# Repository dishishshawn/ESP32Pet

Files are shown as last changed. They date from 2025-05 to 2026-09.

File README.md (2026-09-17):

# ESP32PET

An open-source Tamagotchi, built on an ESP32 with an ST7735 LCD and physical buttons. 
A digital pet resembling me responds to feeding, playing, and dressing up. 
Stats are persistent (saved to EEPROM)

## Features
- Deep sleep (Battery powered use)
- Three-button UI (+ 1 for on and off)
- Designed for portable use

## Hardware Requirements
- ESP32 w/ EEPROM storage (ESP32 DevKit V1)
- Arduino framework (Platform IO)
- TFT LCD (ST7735)
- 3.7V LiPo battery + MCP1700 (3.3V LDO)
- 4x momentary push buttons

## Applications
- KiCAD
- Arduino IDE or PlatformIO

## Additional Notes
Decided to use the full esp32 dev kit for easy testing of new firmware/features.

## Images



## Schematic

**Top level**

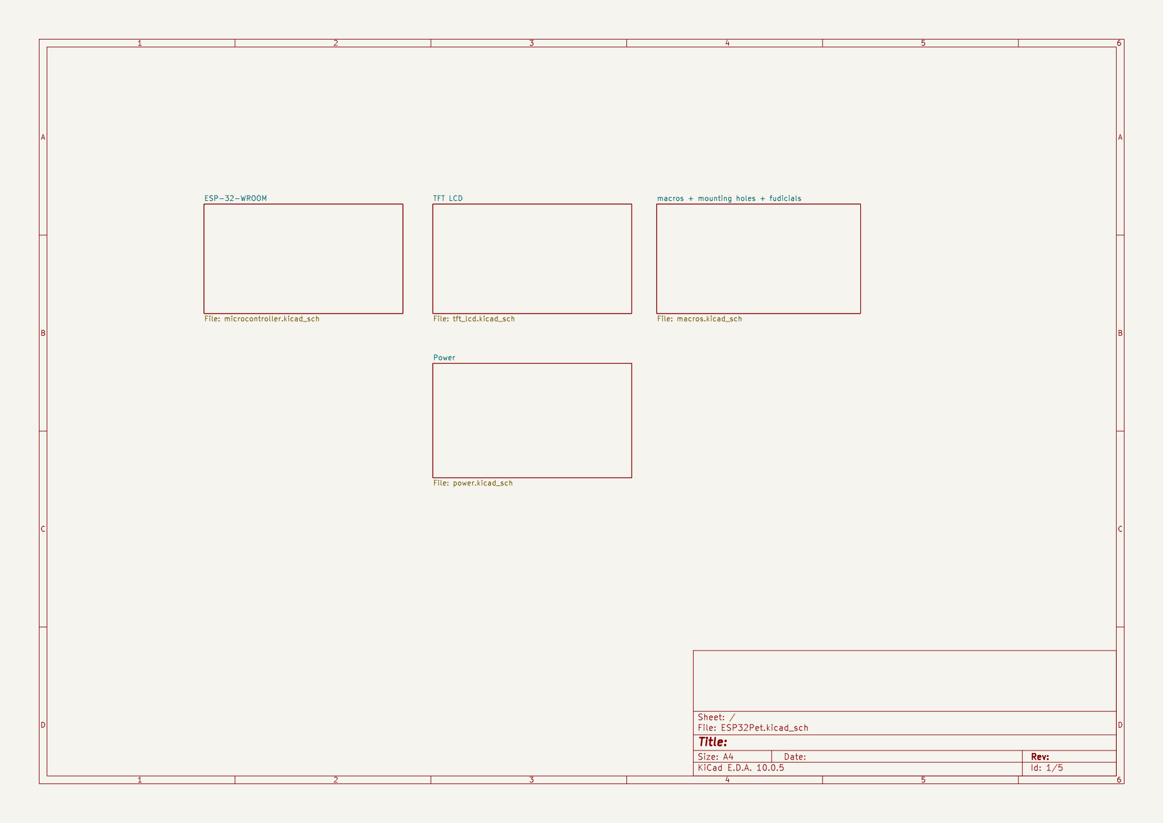
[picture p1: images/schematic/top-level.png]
Top-level schematic


**ESP32**

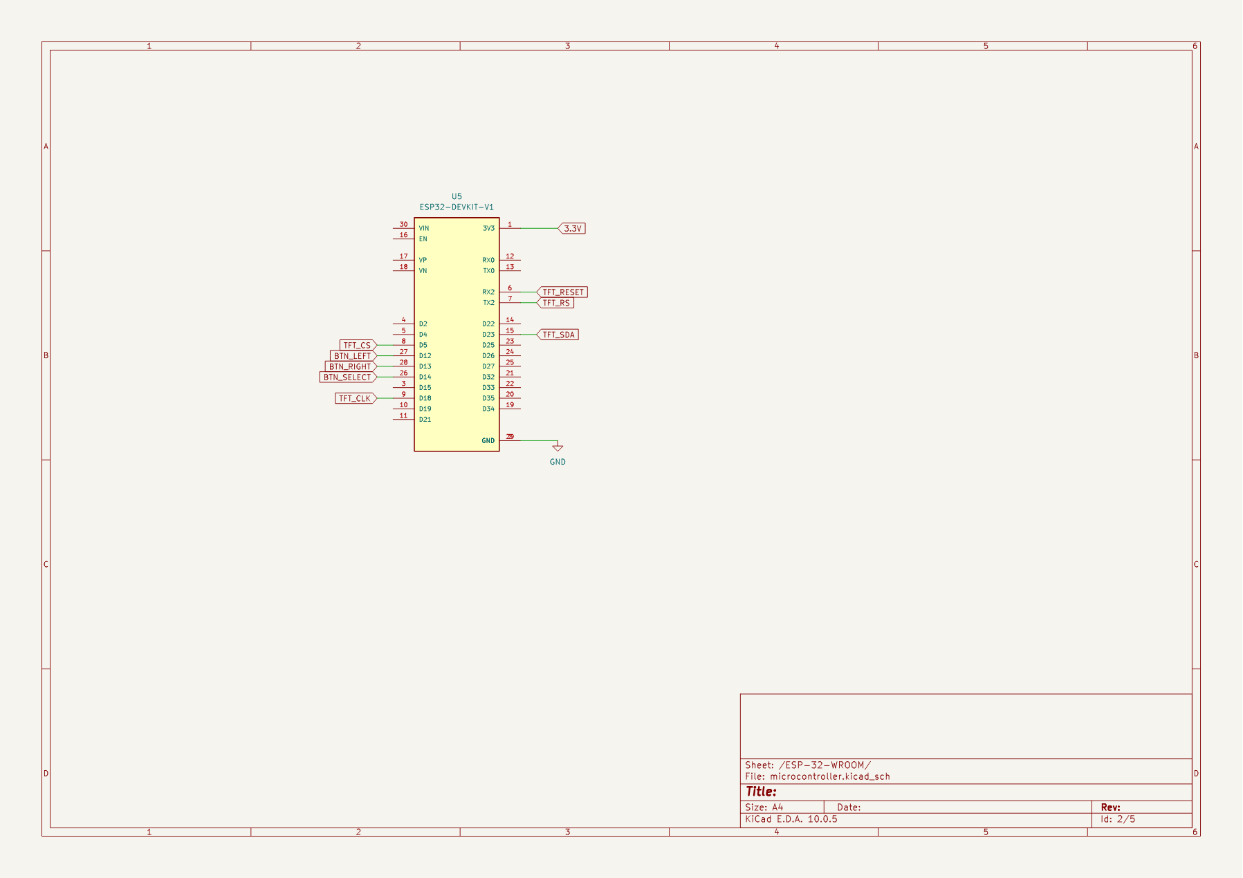
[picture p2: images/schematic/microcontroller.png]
ESP32 schematic


**Power**

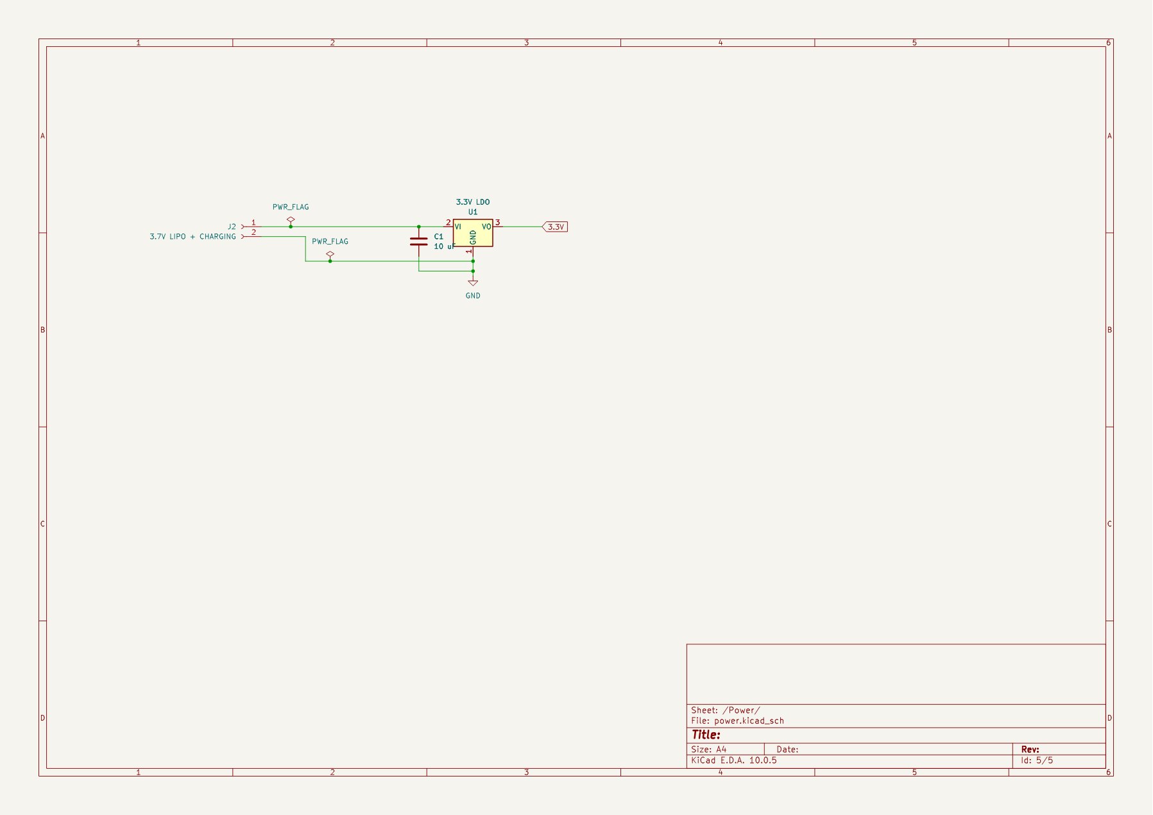
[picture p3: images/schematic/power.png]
Power schematic


**TFT LCD**

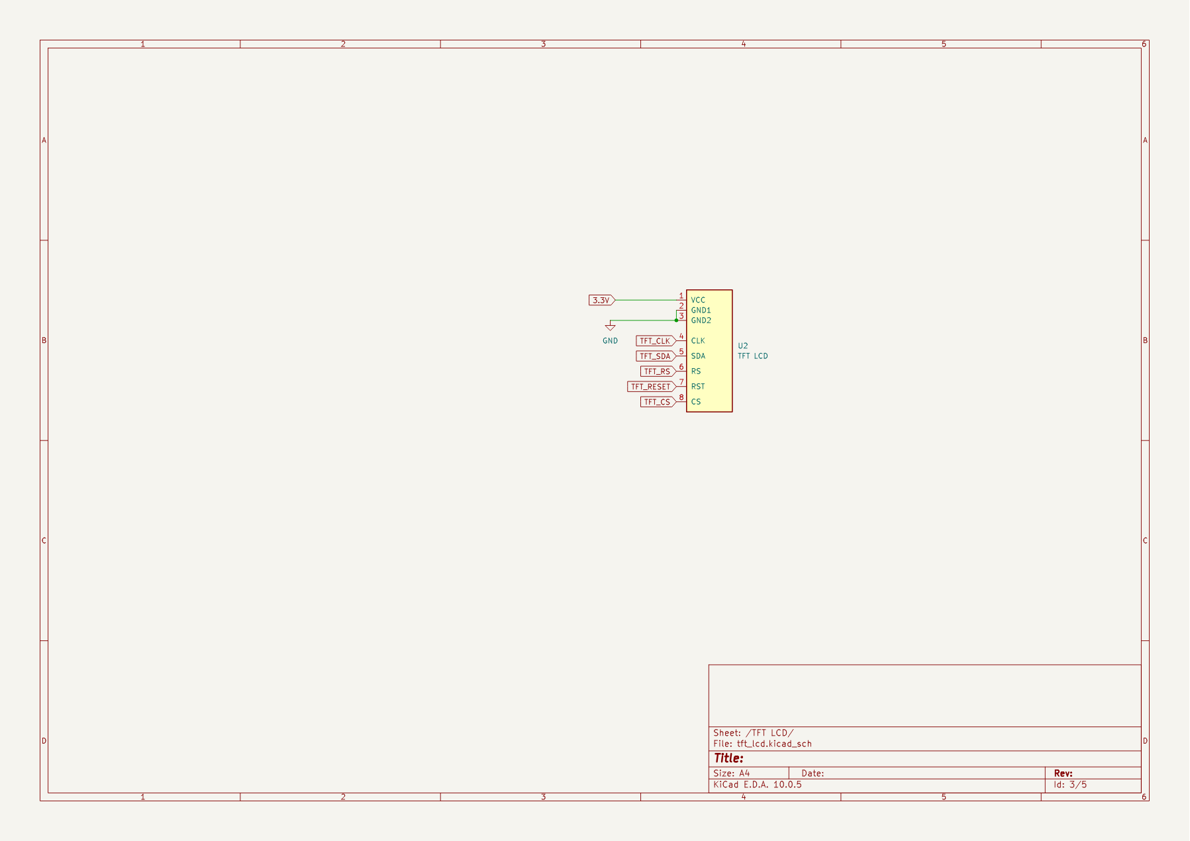
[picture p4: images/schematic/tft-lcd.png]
TFT LCD schematic


## Tamagotchi Case
[OnShape](https://cad.onshape.com/documents/7b0af2517bc8518bf7fb4dfa/w/fc1d8dcb5d67add2eca69795/e/ab74bcbcb7495b5b308ae66d)

## Demo

No demo currently

## Sponsorship


PCBWay sponsors 3D Printing and PCB assembly costs on this project during the prototyping phase!
If you are interested in their awesome fabrication services please check them out.  They offer
3D prototyping, PCB design, and assembly, as well as CNC metal fabrication.  Costs are reasonable and the quality is as good as it gets.  Thank you, PCBWay, for sponsoring me!

## License

MIT

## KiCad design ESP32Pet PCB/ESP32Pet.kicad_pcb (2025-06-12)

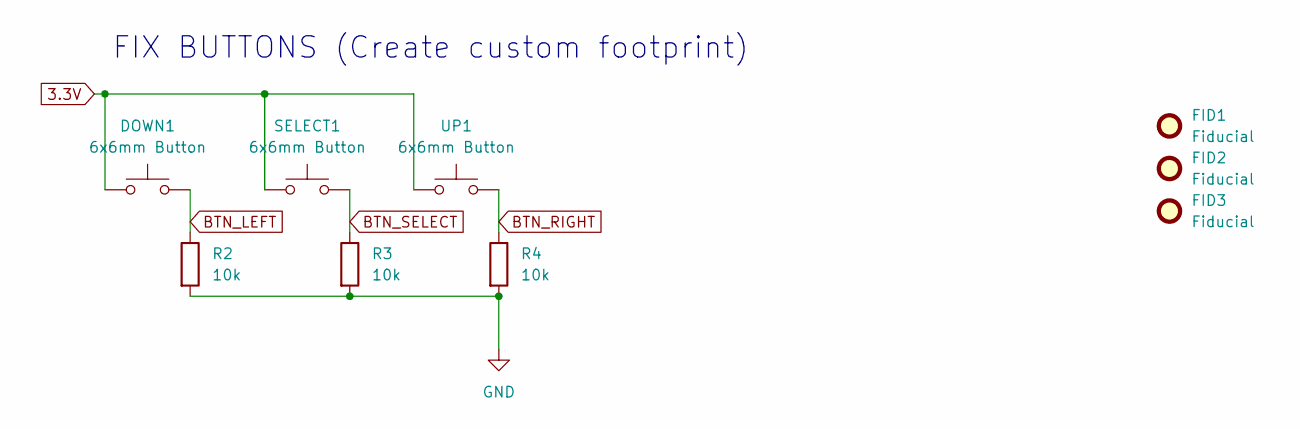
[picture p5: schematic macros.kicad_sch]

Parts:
DOWN1: 6x6mm Button; SW_PUSH_6mm_H5mm
FID1, FID2, FID3: Fiducial; Fiducial_0.5mm_Mask1mm
R2, R3, R4: 10k; R_Axial_DIN0204_L3.6mm_D1.6mm_P7.62mm_Horizontal
SELECT1: 6x6mm Button; SW_PUSH_6mm_H5mm
UP1: 6x6mm Button; SW_PUSH_6mm_H5mm

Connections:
3.3V: DOWN1.1, SELECT1.1, UP1.1; also elsewhere on the board
BTN_LEFT: DOWN1.2, R2.1; also elsewhere on the board
BTN_RIGHT: R4.1, UP1.2; also elsewhere on the board
BTN_SELECT: R3.1, SELECT1.2; also elsewhere on the board
GND: R2.2, R3.2, R4.2; also elsewhere on the board

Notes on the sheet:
FIX BUTTONS (Create custom footprint)

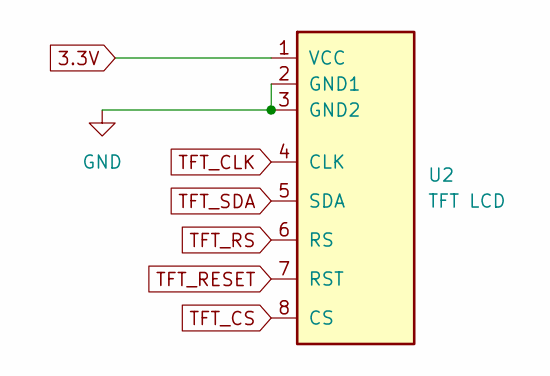
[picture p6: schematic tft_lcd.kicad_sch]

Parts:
U2: TFT LCD; TFT LCD 1.8inch 128x160 w_ SD Card Slot

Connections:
3.3V: U2.1 (VCC); also elsewhere on the board
GND: U2.2 (GND1), U2.3 (GND2); also elsewhere on the board
TFT_CLK: U2.4 (CLK); also elsewhere on the board
TFT_CS: U2.8 (CS); also elsewhere on the board
TFT_RESET: U2.7 (RST); also elsewhere on the board
TFT_RS: U2.6 (RS); also elsewhere on the board
TFT_SDA: U2.5 (SDA); also elsewhere on the board

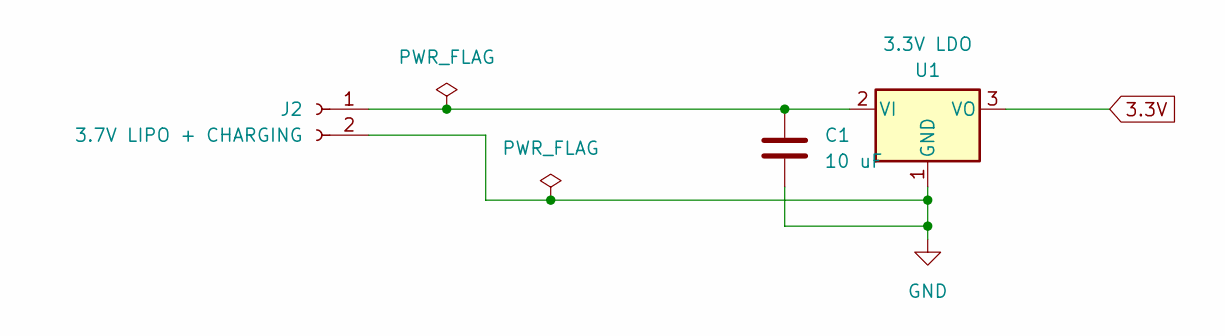
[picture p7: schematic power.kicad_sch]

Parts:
C1: 10 uF; CP_Radial_D4.0mm_P1.50mm
J2: 3.7V LIPO + CHARGING; PinHeader_1x02_P2.54mm_Vertical
U1: 3.3V LDO; TO-92_Inline

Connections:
3.3V: U1.3 (VO); also elsewhere on the board
GND: C1.1, J2.2, U1.1 (GND); also elsewhere on the board
unnamed: C1.2, J2.1, U1.2 (VI)

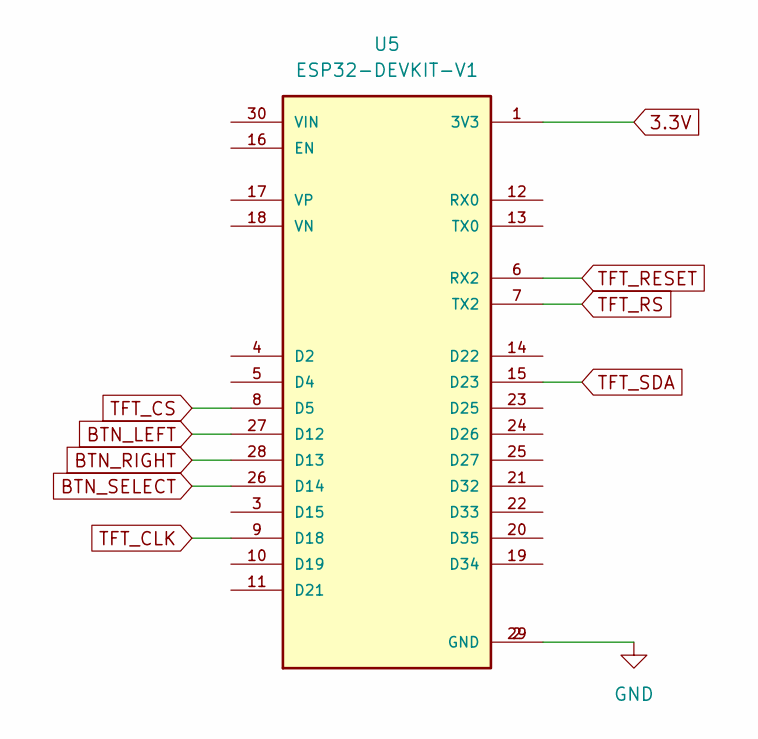
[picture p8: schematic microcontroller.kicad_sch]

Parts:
U5: ESP32-DEVKIT-V1; MODULE_ESP32_DEVKIT_V1; PARTREV N/A

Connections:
3.3V: U5.1 (3V3); also elsewhere on the board
BTN_LEFT: U5.27 (D12); also elsewhere on the board
BTN_RIGHT: U5.28 (D13); also elsewhere on the board
BTN_SELECT: U5.26 (D14); also elsewhere on the board
GND: U5.2 (GND), U5.29 (GND); also elsewhere on the board
TFT_CLK: U5.9 (D18); also elsewhere on the board
TFT_CS: U5.8 (D5); also elsewhere on the board
TFT_RESET: U5.6 (RX2); also elsewhere on the board
TFT_RS: U5.7 (TX2); also elsewhere on the board
TFT_SDA: U5.15 (D23); also elsewhere on the board

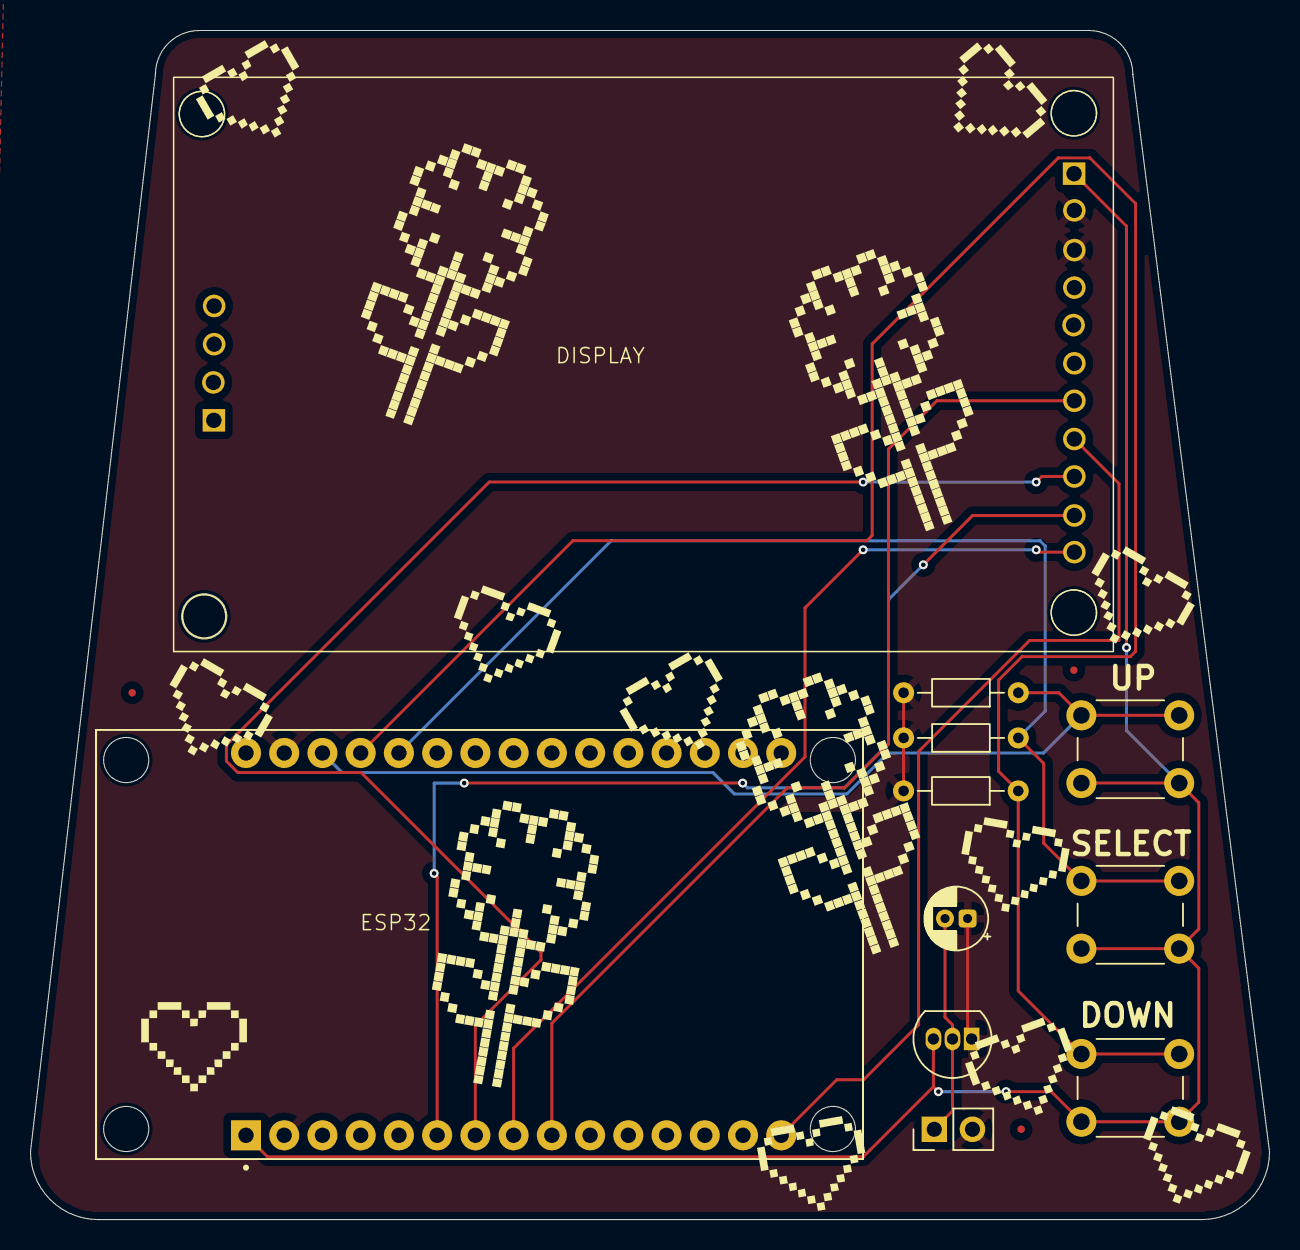
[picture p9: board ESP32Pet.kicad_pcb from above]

Board: 2 copper layers, 82.3 x 79.0 mm, 14 parts (0 on the bottom side), 11 nets.

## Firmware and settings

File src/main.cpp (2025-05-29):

#include <Arduino.h>
#include <TFT_eSPI.h>
#include "esp_task_wdt.h"
#include <EEPROM.h>

#include "gotchi.h"
#include "scroll_menu.h"
#include "sprites.h"

TFT_eSPI tft = TFT_eSPI();
hw_timer_t * timer = NULL;

#define LEFT 14
#define RIGHT 13
#define SELECT 12
#define WAKE_UP_PIN 34

void stateSelection();
void homeFunc();
void sleepFunc();
void dressFunc();
void statsFunc();
void changeState(const char* section);
void displayMenuFunc();
void displayGotchi();
void displaySleep();
void displayEat();
void displayPlay();
void displayCut();
void displayAge();
void displayMenuDress();
void displayStats();
// void IRAM_ATTR watchdogCallback();

ScrollMenu menu(58, 32, 6);
ScrollMenu menuDress(58, 32, 5);
char activeState[20] = "Home";

bool sleeping;
int sleepLevel;
int happiness;
int hunger;
int age;
int beardLength;
int expression;
int clothing;

Gotchi gotchi(false, 0, 0, 0, 0, 0, 0, 0);

unsigned long lastInteraction = 0;
const unsigned long timeoutDuration = 10000;
bool pressed = false;
int frameCount = 0;
int spriteOffset = -1;

#define BAR_W 16
inline void clearOutside() {
    tft.resetViewport();                       // turn clipping OFF
    tft.fillRect(0, 0, BAR_W, 128, TFT_BLACK);           // left bar
    tft.fillRect(160-BAR_W, 0, BAR_W, 128, TFT_BLACK);   // right bar
    tft.setViewport(16, 0, 143, 127, true);    // clipping ON again
}

void setup() {
    Serial.begin(115200);
    EEPROM.begin(32);
    Serial.println("Boot");

    esp_sleep_wakeup_cause_t wakeup_reason = esp_sleep_get_wakeup_cause();
    Serial.print("Wake reason: ");
    Serial.println(wakeup_reason);

    sleeping     = EEPROM.read(0);
    sleepLevel   = EEPROM.read(1);
    happiness    = EEPROM.read(2);
    hunger       = EEPROM.read(3);
    EEPROM.get(10, age);
    beardLength  = EEPROM.read(5);
    expression   = EEPROM.read(6);
    clothing     = EEPROM.read(7);

    gotchi = Gotchi(sleeping, sleepLevel, hunger, happiness, age, beardLength, expression, clothing);

    tft.init(INITR_GREENTAB);
    tft.fillScreen(TFT_BLACK);
    tft.setRotation(1);

    bool flip = true;
    int x0 = 16;
    int y0 = 0;
    int x1 = x0 + 128 - 1;
    int y1 = y0 + 128 - 1;
    tft.setViewport(x0, y0, x1, y1, flip); // Set the viewport to the full screen

    tft.fillScreen(TFT_BLACK);

    pinMode(LEFT, INPUT_PULLDOWN);
    pinMode(RIGHT, INPUT_PULLDOWN);
    pinMode(SELECT, INPUT_PULLDOWN);
    pinMode(WAKE_UP_PIN, INPUT_PULLDOWN);

    frameCount = 50;
    displayGotchi();
    displayMenuFunc();
    displayStats();

    // timer = timerBegin(0, 80, true); 
    // timerAttachInterrupt(timer, &watchdogCallback, true);
    // timerAlarmWrite(timer, 1000000, true); // 1 second
    // timerAlarmEnable(timer);


    // esp_task_wdt_init(40, true); 
    // esp_task_wdt_add(NULL); 

    int debugAge = 0;
    EEPROM.get(10, debugAge);

    Serial.println("Ready to start");
    Serial.printf("EEPROM Read:\n Sleep: %d\n Hunger: %d\n Happiness: %d\n Age: %d\n Beard: %d\n Clothing: %d\n",
        sleepLevel, hunger, happiness, age, beardLength, clothing);
}

// States
int state = 0;
/*
    0 - home
    1 - sleep
    2 - dress
    3 - stats
*/

char menuSections[][20] = {
    "Cut",
    "Dress",
    "Eat",
    "Stats",
    "Play",
    "Sleep",
};

const unsigned char* menuIcons[] = {
    beard_icon,
    dress_icon,
    eat_icon,
    stats_icon,
    play_icon,
    sleep_icon,
};

const unsigned char* bodyArray[] = {
    myBitmapbody_01,
    myBitmapbody_02,
    myBitmapbody_03,
    myBitmapbody_04
};

const unsigned char* menuDressIcons[] = {
    backHome,
    myBitmapbody_01,
    myBitmapbody_02,
    myBitmapbody_03,
    myBitmapbody_04
};

void loop() {
    if (digitalRead(WAKE_UP_PIN) == HIGH) {
        Serial.println("Power button pressed. Going to sleep...");
        
        // Save everything
        gotchi.updateSleeping();  // optional, to show it's sleeping
        EEPROM.write(0, gotchi.sleeping);
        EEPROM.write(1, gotchi.sleep);
        EEPROM.write(2, gotchi.happiness);
        EEPROM.write(3, gotchi.hunger);
        EEPROM.put(10, gotchi.age);
        EEPROM.write(5, gotchi.beardLength);
        EEPROM.write(6, gotchi.expression);
        EEPROM.write(7, gotchi.clothing);
        EEPROM.commit();

        delay(500); // debounce
        tft.fillScreen(TFT_BLACK);
        tft.setCursor(20, 20);
        tft.setTextSize(2);
        tft.setTextColor(TFT_WHITE);
        tft.println("Goodnight...");

        delay(2000);
        esp_sleep_enable_ext0_wakeup(static_cast<gpio_num_t>(WAKE_UP_PIN), LOW);
        esp_deep_sleep_start();
    }

    stateSelection(); 
    delay(10);
}

void stateSelection() {
    if(state == 0){
        homeFunc();
    } else if (state == 1) {
        sleepFunc();
    } else if (state == 2) {
        dressFunc();
    } else if (state == 3) {
        statsFunc();
    }
}

// State functions

void changeState(const char* section){
    tft.drawRoundRect(0, 0, 128, 160, 3, TFT_WHITE); // quick outline
    EEPROM.commit();
    lastInteraction = millis();
    delay(200);
    tft.drawRoundRect(0, 0, 128, 160, 3, TFT_BLACK); // erase it  

    Serial.println(section);
    if(strcmp(section, "Sleep") == 0){
        gotchi.updateSleeping();
        gotchi.updateHappiness(0);
        gotchi.updateSleep(0);
        tft.fillRect(0, 16, 128, 160, TFT_BLACK);
        state = 1;
    } else if(strcmp(section, "Play") == 0){
        gotchi.updateHappiness(4);
        gotchi.updateSleep(-2);
        gotchi.updateHunger(-2);
        displayPlay();
    } else if(strcmp(section, "Stats") == 0){
        displayAge();
        state = 3;
    } else if(strcmp(section, "Eat") == 0){
        gotchi.updateHunger(5);
        gotchi.updateHappiness(1);
        displayEat();
    } else if(strcmp(section, "Cut") == 0){
        gotchi.updateBeardLength(0);
        if(gotchi.beardLength >= 24){
        gotchi.updateHappiness(10);
        }
        displayCut();
    } else if(strcmp(section, "Dress") == 0){
        tft.fillRect(0, 16, 128, 48, TFT_BLACK);
        displayMenuDress();
        state = 2;
    } else if(strcmp(section, "Home") == 0){
        frameCount = 50;
        tft.fillRect(0, 16, 128, 48, TFT_BLACK);
        displayMenuFunc();
        displayGotchi();
        state = 0;
    }
    for (int i = 0; i < 20; i++){
    activeState[i] = section[i]; 
    }
    pressed = false;
    displayStats();
}

void homeFunc() {
    if(pressed == false) {
        if(digitalRead(SELECT) == HIGH) {
            pressed = true;
            changeState(menuSections[menu.activeSection]);
    } else if(digitalRead(LEFT) == HIGH) {
            pressed = true;
            menu.moveLeft();
            displayMenuFunc();
        } else if(digitalRead(RIGHT) == HIGH) {
            pressed = true;
            menu.moveRight();
            displayMenuFunc();
        }
    } else if(digitalRead(SELECT) == LOW && digitalRead(LEFT) == LOW && digitalRead(RIGHT) == LOW) {
            pressed = false;
        }
    displayGotchi();
}

void sleepFunc() {
    if(!gotchi.sleeping) {
        changeState("Home");
    }

    if(!pressed) {
        if(digitalRead(SELECT) == HIGH) {
            pressed = true;
            gotchi.updateSleeping();
            gotchi.updateHappiness(-3);
            changeState("Home");
        } else if(digitalRead(SELECT) == LOW && digitalRead(LEFT) == LOW && digitalRead(RIGHT) == LOW) {
        pressed = false;
    }
    displaySleep();
    }
}

void dressFunc() {

    if (!pressed) {

        if (digitalRead(SELECT) == HIGH) {          // SELECT
            pressed = true;

            if (menuDress.activeSection == 0) {     // “← Home”
                changeState("Home");
            } else {                                // one of the outfits
                gotchi.updateClothing(menuDress.activeSection - 1);
                changeState("Home");
            }

        } else if (digitalRead(LEFT) == HIGH) {     // LEFT
            pressed = true;
            menuDress.moveLeft();
            displayMenuDress();

        } else if (digitalRead(RIGHT) == HIGH) {    // RIGHT
            pressed = true;
            menuDress.moveRight();
            displayMenuDress();
        }
    }

    else if (digitalRead(SELECT) == LOW &&
             digitalRead(LEFT)   == LOW &&
             digitalRead(RIGHT)  == LOW) {
        pressed = false;
    }
}

void statsFunc(){
  if(pressed == false){
    if(digitalRead(SELECT) == HIGH){
      pressed = true;
      changeState("Home");    
    }
  }else if(digitalRead(SELECT) == LOW && digitalRead(LEFT) == LOW && digitalRead(RIGHT) == LOW){
    pressed = false;
  }  
}

void displayMenuFunc()
{
    int y = 17;
    const int rowH = 16;

    tft.fillRect(51, 17, 77, 47, TFT_BLACK);
    tft.setTextColor(TFT_WHITE, TFT_BLACK);
    tft.setTextSize(1);

    /* ── previous ─────────────────────────── */
    tft.setCursor(menu.x + 19, y + 4);
    tft.println(menuSections[ menu.prev() ]);
    tft.drawBitmap(menu.x, y + 3, menuIcons[ menu.prev() ], 10, 10, 1);

    /* ── active ───────────────────────────── */
    y += rowH;
    tft.drawRoundRect(menu.x - 5, y, 73, rowH, 3, TFT_WHITE);
    tft.setCursor(menu.x + 19, y + 4);
    tft.println(menuSections[ menu.activeSection ]);
    tft.drawBitmap(menu.x, y + 3, menuIcons[ menu.activeSection ], 10, 10, 1);

    /* ── next ─────────────────────────────── */
    y += rowH;
    tft.setCursor(menu.x + 19, y + 4);
    tft.println(menuSections[ menu.next() ]);
    tft.drawBitmap(menu.x, y + 3, menuIcons[ menu.next() ], 10, 10, 1);
}

// void displayMenuFunc(){
//   int y = 17;
//   int height = 16;

//   tft.fillRect(51, 17, 77, 47, TFT_BLACK);
//   tft.setTextColor(TFT_WHITE, TFT_BLACK);
  
//   tft.setTextSize(1);

//   //PREV SECTION
//   tft.setCursor(menu.x + 19, y + 4);
//   tft.println(menuSections[menu.prev()]);
//   tft.drawBitmap(menu.x, y + 3, menuIcons[menu.prev()], 10, 10, 1);

//   //ACTIVE SECTION
//   y = y + height;
//   tft.drawRoundRect(menu.x - 5, y, 73, 16, 3, TFT_WHITE);
//   tft.setCursor(menu.x + 19, y + 4);
//   tft.println(menuSections[menu.next()]);
//   tft.drawBitmap(menu.x, y + 3, menuIcons[menu.next()], 10, 10, 1);

//   //NEXT SECTION
//   y = y + height;
//   tft.setCursor(menu.x + 19, y + 4);
//   tft.println(menuSections[menu.nextSection]);
//   tft.drawBitmap(menu.x, y + 3, menuIcons[menu.nextSection], 10, 10, 1);
// }


void displayMenuDress(){
  tft.fillRect(1, 17, 127, 47, TFT_BLACK);

  // PREV CLOTHING
  tft.drawBitmap(3, 17, menuDressIcons[menuDress.prev()], 32, 46, TFT_WHITE);

  // DISPLAY ALE WITH CHANGING CLOTHING
  tft.drawRoundRect(39, 16, 50, 48, 5, TFT_WHITE);
  
  int spriteX = 39 + 10;
  
  if(menuDress.activeSection != 0){
    tft.fillRect(spriteX, 18, 32, 46, TFT_BLACK);
    tft.drawBitmap(spriteX, 18, menuDressIcons[menuDress.activeSection], 32, 46, TFT_WHITE);
  
    tft.drawBitmap(spriteX, 18, feet_bg, 32, 46, TFT_BLACK);
    tft.drawBitmap(spriteX, 18, feet, 32, 46, TFT_WHITE);
    
    tft.drawBitmap(spriteX, 18, head_bg, 32, 46, TFT_BLACK);
    tft.drawBitmap(spriteX, 18, head, 32, 46, TFT_WHITE);
    
    if(gotchi.beardLength >= 24){
      tft.drawBitmap(10, 18 + spriteOffset, beard_bg, 32, 46, TFT_BLACK);
      tft.drawBitmap(10, 18 + spriteOffset, beard, 32, 46, TFT_WHITE);
    }
    
    tft.drawBitmap(spriteX, 18, eyes, 32, 46, TFT_BLACK);
  }else{
    tft.fillRect(spriteX, 18, 32, 46, TFT_BLACK);
    tft.drawBitmap(spriteX, 18, menuDressIcons[menuDress.activeSection], 32, 46, TFT_WHITE);
  }
  
  
  // NEXT CLOTHING
  tft.drawBitmap(93, 17, menuDressIcons[menuDress.next()], 32, 46, TFT_WHITE);
}

void displayGotchi(){

  if(frameCount >= 50){
    tft.drawRoundRect(0, 16, 50, 48, 5, TFT_WHITE);
    
    tft.fillRect(10, 18, 32, 46, TFT_BLACK);
    
    tft.drawBitmap(10, 18 + spriteOffset, bodyArray[gotchi.clothing], 32, 46, TFT_WHITE);
  
    tft.drawBitmap(10, 18, feet_bg, 32, 46, TFT_BLACK);
    tft.drawBitmap(10, 18, feet, 32, 46, TFT_WHITE);

    tft.drawBitmap(10, 18 + spriteOffset, head_bg, 32, 46, TFT_BLACK);
    tft.drawBitmap(10, 18 + spriteOffset, head, 32, 46, TFT_WHITE);
    
    if(gotchi.beardLength >= 24){
      tft.drawBitmap(10, 18 + spriteOffset, beard_bg, 32, 46, TFT_BLACK);
      tft.drawBitmap(10, 18 + spriteOffset, beard, 32, 46, TFT_WHITE);
    }

    tft.drawBitmap(10, 18 + spriteOffset, eyes, 32, 46, TFT_BLACK);
      
    
    if(spriteOffset == -1){
      spriteOffset = -2;
    }else{   
      spriteOffset = -1;
    }
    frameCount = 0;
  }
  frameCount++;
    
}

void displaySleep(){

  if(frameCount >= 50){
    tft.fillRect(0, 16, 128, 48, TFT_BLACK);
    tft.setTextColor(TFT_WHITE, TFT_BLACK);
    tft.setTextSize(1);
    tft.setCursor(64 - spriteOffset, 33 - spriteOffset);
    tft.println("Z");
    tft.setCursor(59 - !spriteOffset, 46 - !spriteOffset);
    tft.println("Z");
    tft.setTextSize(2);
    tft.setCursor(47 - spriteOffset, 26 - !spriteOffset);
    tft.println("Z");
      
    
    spriteOffset = !spriteOffset;
    frameCount = 0;
  }
  frameCount++;    
}

void selectEatFrame(int x, int y, int n){
  if(gotchi.beardLength >= 24){
    if(n == 1){
      tft.drawBitmap(x, y, eat_anim_head_b_1, 45, 40, TFT_WHITE);
    }else{
      tft.drawBitmap(x, y, eat_anim_head_b_2, 45, 40, TFT_WHITE);
    }  
  }else{
    if(n == 1){
      tft.drawBitmap(x, y, eat_anim_head_n_1, 45, 40, TFT_WHITE);
    }else{
      tft.drawBitmap(x, y, eat_anim_head_n_2, 45, 40, TFT_WHITE);
    }    
  }
  
}

void displayEat(){

  int startX = 30;
  int startY = 20;

  tft.fillRect(0, 16, 128, 48, TFT_BLACK); // Clear screen

  // Frame 1
  selectEatFrame(startX,startY,1);
  tft.drawBitmap(startX + 50, startY + 15, eat_anim_food_1, 15, 15, TFT_WHITE);
  

  delay(500);

  // Frame 2
  tft.fillRect(0, 16, 45 + startX, 48, TFT_BLACK);
  selectEatFrame(startX,startY,2); 
  

  delay(500);

  // Frame 3
  tft.fillRect(0, 16, 45 + startX, 48, TFT_BLACK);
  tft.fillRect(45 + startX, 16, 55 + startX, 48, TFT_BLACK);
  selectEatFrame(startX,startY,1);
  tft.drawBitmap(startX + 50, startY + 15, eat_anim_food_2, 15, 15, TFT_WHITE);
  

  delay(500);

  // Frame 4
  tft.fillRect(0, 16, 45 + startX, 48, TFT_BLACK);
  selectEatFrame(startX,startY,2);
  

  delay(500);

  // Frame 5
  tft.fillRect(0, 17, 128, 48, TFT_BLACK);
  tft.fillRect(45 + startX, 16, 55 + startX, 48, TFT_BLACK);
  selectEatFrame(startX,startY,1);
  tft.drawBitmap(startX + 50, startY + 15, eat_anim_food_3, 15, 15, TFT_WHITE);
  

  delay(500);

  // Frame 6
  tft.fillRect(0, 16, 45 + startX, 48, TFT_BLACK);
  selectEatFrame(startX,startY,2);
  

  delay(500);

  // Frame 7
  tft.fillRect(0, 17, 128, 48, TFT_BLACK);
  tft.fillRect(45 + startX, 16, 55 + startX, 48, TFT_BLACK);
  selectEatFrame(startX,startY,1);
  
  esp_task_wdt_reset();

  delay(500);
  delay(500);

  changeState("Home");
  
}

//__________________________________________________ PLAY ANIMATION

void displayPlay(){
  int startX = 50;
  int startY = 17;
  int loop = 2;
  
  for (int i = 0; i <= loop; i++) {
    // Frame 1
    tft.fillRect(0, 16, 128, 48, TFT_BLACK); // Clear Screen
    tft.drawBitmap(startX, startY, play_anim_1, 27, 48, TFT_WHITE);
     
    delay(200);

    // Frame 2
    tft.fillRect(0, 16, 128, 48, TFT_BLACK);
    tft.drawBitmap(startX, startY, play_anim_2, 27, 48, TFT_WHITE);
    
    delay(200);

    // Frame 3
    tft.fillRect(0, 16, 128, 48, TFT_BLACK);
    tft.drawBitmap(startX, startY, play_anim_3, 27, 48, TFT_WHITE);
    
    delay(200);

    // Frame 4
    tft.fillRect(0, 16, 128, 48, TFT_BLACK);
    tft.drawBitmap(startX, startY, play_anim_4, 27, 48, TFT_WHITE);
    
    delay(200);

    // Frame 5
    tft.fillRect(0, 16, 128, 48, TFT_BLACK);
    tft.drawBitmap(startX, startY, play_anim_5, 27, 48, TFT_WHITE);
    
    delay(200);
  }
  
  delay(500);

  changeState("Home");
  
}

//__________________________________________________ CUT ANIMATION

void displayCut(){
  int startX = 45;
  int startY = 24;
  int loop = 2;
  
  for (int i = 0; i <= loop; i++) {
    // Frame 1
    tft.fillRect(0, 16, 128, 48, TFT_BLACK); // Clear Screen 
    tft.drawBitmap(startX, startY, cut_anim_1, 37, 28, TFT_WHITE);
     
    delay(500);

    // Frame 2
    tft.fillRect(0, 16, 128, 48, TFT_BLACK);
    tft.drawBitmap(startX, startY, cut_anim_2, 37, 28, TFT_WHITE);
    
    delay(500);

  }
  
  delay(500);

  changeState("Home");
  
}

//__________________________________________________ DISPLAY AGE

void displayAge(){
  tft.fillRect(0, 16, 128, 48, TFT_BLACK);

  tft.setTextSize(1);
  
  tft.setCursor(10,20);
  tft.setTextColor(TFT_BLACK, TFT_WHITE);
  tft.print("Name");
  tft.setTextColor(TFT_WHITE);
  tft.println(" Shawn");
  
  tft.setCursor(10,32);
  tft.setTextColor(TFT_BLACK, TFT_WHITE);
  tft.print("Age");
  tft.setTextColor(TFT_WHITE);
  tft.print(" ");
  tft.print(gotchi.age/24);
  tft.println(" days");

  tft.setCursor(10,44);
  tft.setTextColor(TFT_BLACK, TFT_WHITE);
  tft.print("Weight");
  tft.setTextColor(TFT_WHITE);
  tft.println(" 88 kg");
}


//__________________________________________________ STATS DISPLAY

void displayStats(){

  tft.fillRect(1, 1, 127, 15, TFT_BLACK);
  tft.setTextSize(1);

  // HAPPINESS STATS
  tft.setCursor(2,5);
  tft.println("H");
  tft.drawRoundRect(9, 6, 27, 6, 1, TFT_WHITE);
  int H = gotchi.mapValue(gotchi.happiness, 27);
  tft.fillRect(10, 7, H, 4, TFT_WHITE);

  // SLEEP STATS
  tft.setCursor(43,5);
  tft.println("S");
  tft.drawRoundRect(50, 6, 27, 6, 1, TFT_WHITE);
  int S = gotchi.mapValue(gotchi.sleep, 27);
  tft.fillRect(51, 7, S, 4, TFT_WHITE);

  // HUNGER/FOOD STATS
  tft.setCursor(85,5);
  tft.println("F");
  tft.drawRoundRect(92, 6, 27, 6, 1, TFT_WHITE);
  int F = gotchi.mapValue(gotchi.hunger, 27);
  tft.fillRect(93, 7, F, 4, TFT_WHITE);
  
  
}

// Timer
// int hour = 40; 
// void IRAM_ATTR watchdogCallback() {
//     sec++;
//     Serial.print("sec: ");
//     Serial.println(sec);

//     if (sec > hour) {
//         sec = 0;

//         gotchi.updateAge();
//         gotchi.updateHappiness(-1);
//         gotchi.updateHunger(-1);
//         gotchi.updateBeardLength(gotchi.beardLength + 1);
//         gotchi.updateSleep(gotchi.sleeping ? 3 : -1);

//         // Save everything and go to sleep
//         EEPROM.commit();

//         Serial.println("Going to deep sleep...");
//         esp_sleep_enable_ext0_wakeup(static_cast<gpio_num_t>(WAKE_UP_PIN), LOW);
//         esp_deep_sleep_start();
//     }
// }


void turnOn() {
  Serial.println("TURN ON");
  delay(2000);
}

void turnOff() {
    tft.fillScreen(TFT_BLACK);
    tft.setTextColor(TFT_WHITE, TFT_BLACK);
    tft.setTextSize(2);
    tft.setCursor(20, 30);
    tft.println("Goodbye!");

    delay(2000);

    // Save data to EEPROM
    EEPROM.write(0, gotchi.sleeping);
    EEPROM.write(1, gotchi.sleep);
    EEPROM.write(2, gotchi.happiness);
    EEPROM.write(3, gotchi.hunger);
    EEPROM.put(10, gotchi.age);
    EEPROM.write(5, gotchi.beardLength);
    EEPROM.write(6, gotchi.expression);
    EEPROM.write(7, gotchi.clothing);
    EEPROM.commit(); 
    Serial.println("Data saved to EEPROM");

    Serial.println("Entering deep sleep...");
    // esp_sleep_enable_ext0_wakeup(static_cast<gpio_num_t>(WAKE_UP_PIN), LOW); // Cast WAKE_UP_PIN to gpio_num_t
    // esp_deep_sleep_start();
}

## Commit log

2025-05-28 Display works, needs to be scaled to fit screen, and there are visual bugs
    [main.cpp]
2025-05-29 Working eat, play, cut screens, but dress screen isn't working. Also, sleep isn't functional
2025-05-29 Fixed and centered the menu
    [main.cpp]
2025-05-29 Semi-working memory, it reads correctly on startup, but values are reset right after
    [main.cpp]
2025-06-01 Added KiCAD files
    [ESP32Pet.kicad_pcb, ESP32Pet.kicad_sch, battery_logic.kicad_sch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]
2025-06-03 Schematic Updated
    [ESP32Pet.kicad_sch, macros.kicad_sch, microcontroller.kicad_sch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]
2025-06-03 Schematic complete, created custom footprints and symbols for TFT LCD
    [macros.kicad_sch, microcontroller.kicad_sch, power.kicad_sch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]
2025-06-03 PCB Design Complete
    [ESP32Pet.kicad_pcb, macros.kicad_sch, microcontroller.kicad_sch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]
2025-06-12 Updated ST7735S Footprint for bigger through holes
    [ESP32Pet.kicad_pcb, macros.kicad_sch]
2025-06-12 Updated ST7735 footprint
2026-09-17 Add schematics to README
